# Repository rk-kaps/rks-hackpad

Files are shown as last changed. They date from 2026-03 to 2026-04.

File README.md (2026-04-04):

<h1 align="center">12-Key RP2040 Hackpad</h1>

<p align="center">
  A custom 12-key macropad built around the Seeed XIAO RP2040, featuring per-key RGB, an OLED display, and a 3D printed case.
</p>

<p align="center">
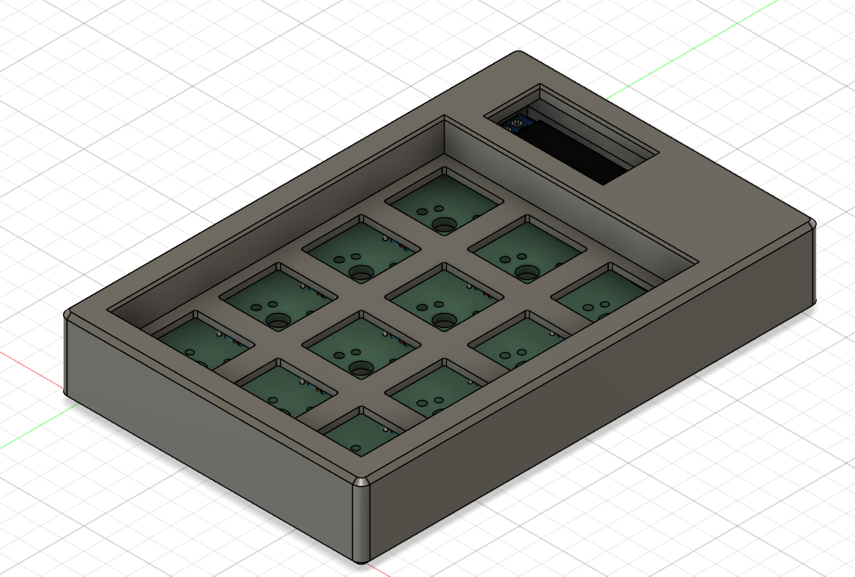
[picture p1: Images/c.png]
Hackpad Main
  
</p>

<hr>

<h2>Motivation</h2>
<ul>

This Hackpad began as a simple volume controller. It evolved into a fully-featured macropad focused on:

- Speeding up workflows
- Reducing repetitive actions
- Providing intuitive visual feedback
- Maximizing functionality within hardware constraints

</ul>

<h2>Project Highlights</h2>
<ul>

- Dual-core RP2040 at up to 133MHz via the compact Seeed XIAO form factor
- Per-key RGB lighting using SK6812 MINI-E reverse-mount LEDs for clean underglow
- 0.91" OLED display for real-time visual feedback and animations
- Keyboard matrix protected by 1N4148 diodes for reliable n-key rollover
- Brass heatset inserts for durable, reusable screw connections in the 3D printed case
- Compact 12-key layout in a custom 3D printed two-piece shell

</ul>

<h2>Firmware Features</h2>
<ul>

- Acts as a USB numpad  
- LED pulses under each key when pressed  
- OLED plays a cat GIF on loop  

</ul>

<hr>

<h2>PCB & Schematic</h2>

<p align="center">
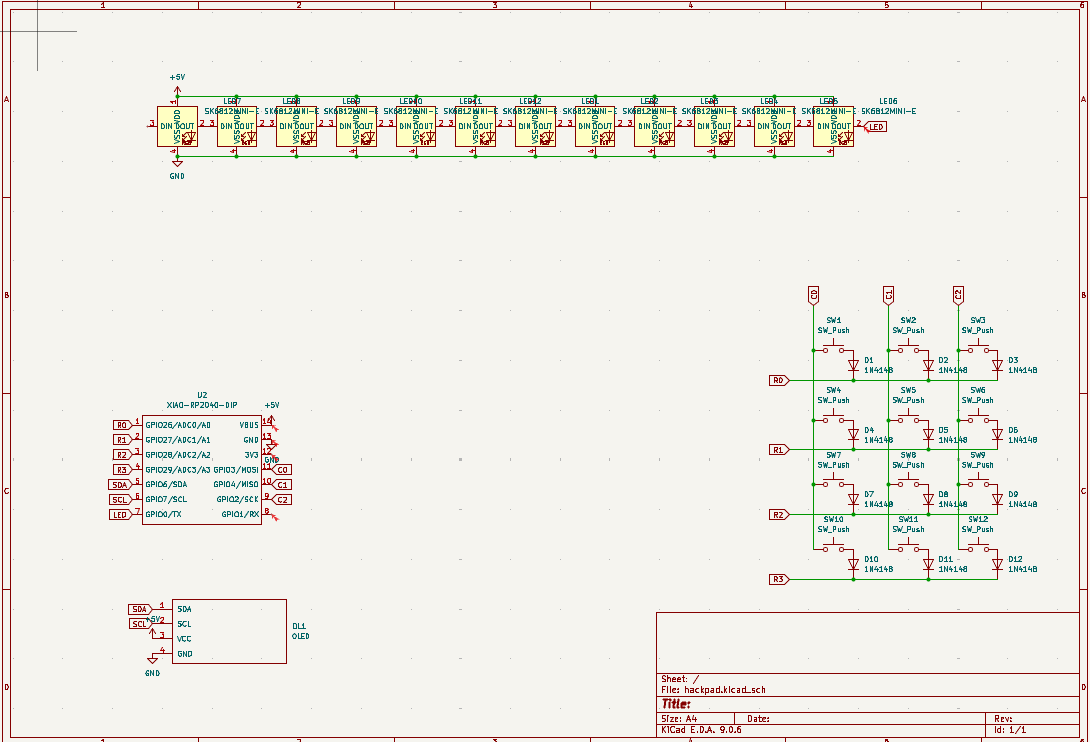
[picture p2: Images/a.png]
Schematic
  
  <br><em>Schematic</em>
</p>

<p align="center">
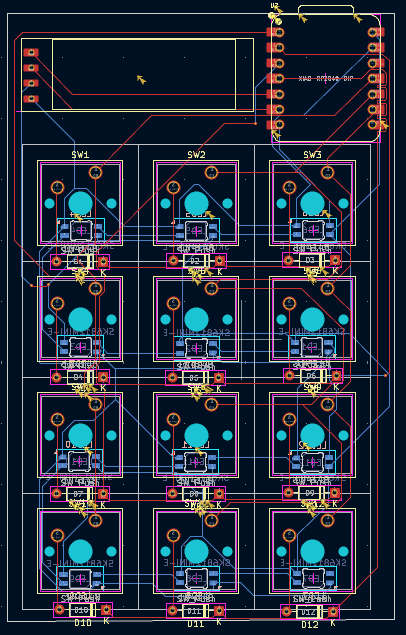
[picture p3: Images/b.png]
PCB Layout
  
  <br><em>PCB Layout (KiCad)</em>
</p>

<p align="center">
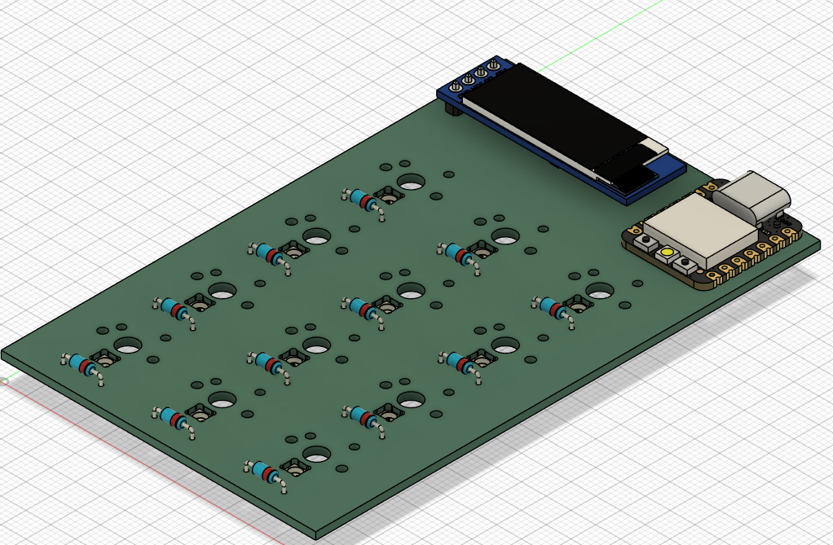
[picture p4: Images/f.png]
PCB 3D View
  
  <br><em>PCB 3D Render</em>
</p>

<hr>

<h2>Case Design</h2>

<p align="center">
  Case CAD
  <br><em>Case CAD</em>
</p>

<hr>

<h2>Bill of Materials</h2>

> A full BOM with pricing and purchase links is available as a separate file.

| Part | Quantity |
|---|---|
| Seeed XIAO RP2040 | 1 |
| MX-Style Switches | 12 |
| Through-hole 1N4148 Diodes | 12 |
| SK6812 MINI-E LEDs | 12 |
| 0.91" OLED Display (SSD1306 I2C 128×32) | 1 |
| Blank DSA Keycaps | 12 |
| M3×16 mm Cap Head Screws | 4 |
| M3×5 mm Brass Heatset Inserts | 4 |
| 3D Printed Case Top | 1 |
| 3D Printed Case Bottom | 1 |

<hr>

<h2>Firmware</h2>

Firmware is located in the `Deploy` folder. Flash directly to the RP2040 via USB drag-and-drop.

<hr>

<h2>Acknowledgements</h2>
<ul>

- Good people of Hack Club  

</ul>

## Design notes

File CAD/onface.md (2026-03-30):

https://cad.onshape.com/documents/341b59d3e8adaa2c605d270c/w/1172ec9e4d3fff75a9b2d15b/e/0eea5737da17a0d97b459e8b <---- link for onface

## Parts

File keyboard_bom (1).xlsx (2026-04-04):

Macropad Keyboard Build — Bill of Materials (India)
# | Part | Qty | Unit | Description | Unit Price (₹) | Total Price (₹) | Supplier | Buy Link
1 | Seeed XIAO RP2040 | 1 | pcs | Dual-core RP2040 MCU, USB-C, compact dev board for keyboard firmware | ₹619 | ₹619 | Robocraze | Buy Here → (https://robocraze.com/products/seeed-studio-xiao-rp2040-development-board)
2 | MX-Style Switches | 12 | pcs | Mechanical keyboard switches (Cherry MX or compatible clone, plate-mount) | ₹35 | ₹750 | Meckeys | Buy Here → (https://meckeys.com/shop/accessories/keyboard-accessories/key-switches/cherry-mx2a-switch/)
3 | Through-hole 1N4148 Diodes | 12 | pcs | Fast switching silicon diode for keyboard matrix (through-hole) | ₹3 | ₹60 | Robocraze | Buy Here → (https://robocraze.com/products/1n4148-diode-pack-of-10)
4 | PCB | 1 | pcs | pcb | ₹230.89 | ₹230.89 | jlcpcb
5 | 0.91" OLED Display (I2C) | 1 | pcs | 128×32 blue OLED display module, I2C, SSD1306 driver | ₹160 | ₹160 | Robocraze | Buy Here → (https://robocraze.com/products/0-91-inch-blue-oled-display-module)
6 | Blank DSA Keycaps | 12 | pcs | Blank PBT DSA profile keycaps, 1u, MX-compatible | ₹100 | ₹1200 | Meckeys | Buy Here → (https://meckeys.com/shop/accessories/keyboard-accessories/keycaps/blank-dsa-keycaps-1u/)
7 | M3×16 mm Screws | 4 | pcs | M3×16mm Socket Head Cap Screws (Allen drive, stainless steel) for case assembly | ₹50 | ₹50 | OnlyScrews | Buy Here → (https://onlyscrews.in/products/m3-x-16mm-hex-allen-csk-high-tensile10-9-black-oxide-screw-dia-3mm-length-16mm)
8 | M3×5 mm Heatset Inserts | 4 | pcs | Brass M3×5mm heatset threaded inserts for 3D-printed case bottom | ₹40 | ₹40 | OnlyScrews | Buy Here → (https://onlyscrews.in/products/m3-x-5mm-brass-threaded-inserts-dia-3mm-length-5mm?variant=50139409973561)
9 | Case Top (3D Printed) | 1 | pcs | Top shell of keyboard case — 3D print using PLA/PETG from your own design files | ₹200 | ₹200 | Local 3D Print Service
10 | Case Bottom (3D Printed) | 1 | pcs | Bottom shell of keyboard case — 3D print using PLA/PETG from your own design files | ₹200 | ₹200 | Local 3D Print Service
 | GRAND TOTAL |  |  |  |  | ₹3231

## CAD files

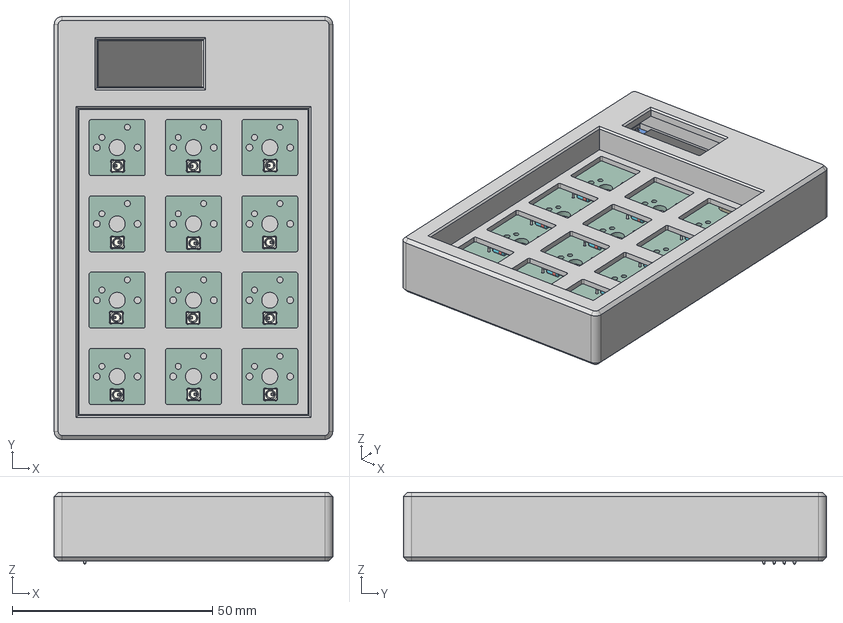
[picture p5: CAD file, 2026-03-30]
CAD/hackpad (2).step
69.5 x 105.6 x 18.0 mm
D_DO-35_SOD27_P7.62mm_Horizontal x 12
LED_SK6812MINI-E x 12
hackpad_PCB
Tiny stuff
LED
LED_1
Programmer port or something
USB-C bits
Power probably
Right
Left
OLED_0.91_128x32
Pin Header 4 x 1 TH 2.54mm Pitch
RESC-0603 x 13
2SD0601A

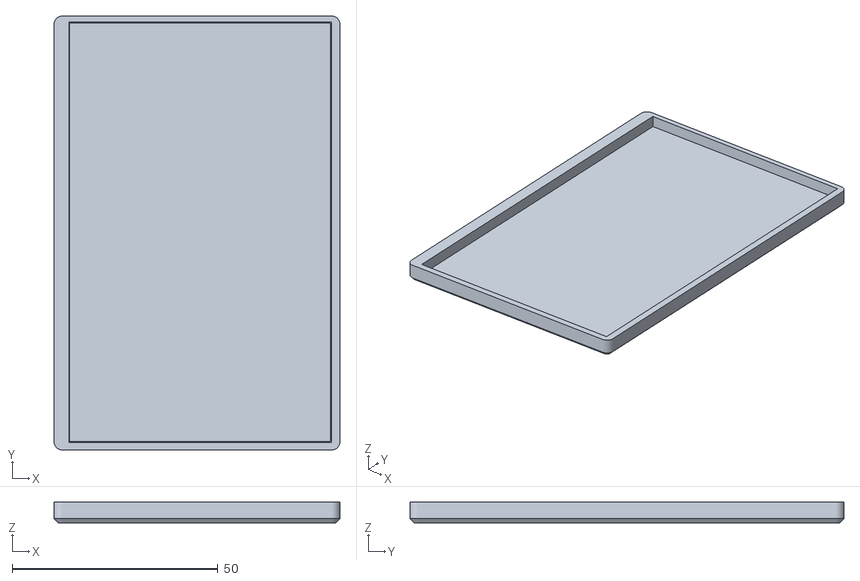
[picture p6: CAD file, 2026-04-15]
CAD/split hackpad/hackpad base2.obj
69.5 x 105.6 x 5.00

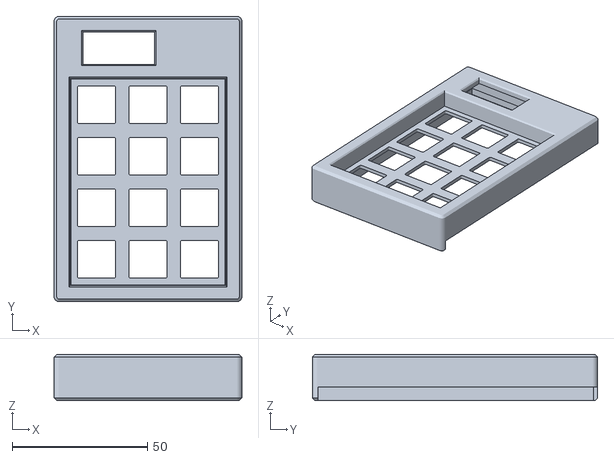
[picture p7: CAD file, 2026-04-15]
CAD/split hackpad/hackpad-hackpada v3 v1Cut.obj
69.5 x 105.6 x 17.2

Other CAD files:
CAD/split hackpad/hackpad sidepanel.obj
CAD/hackpad_.f3d

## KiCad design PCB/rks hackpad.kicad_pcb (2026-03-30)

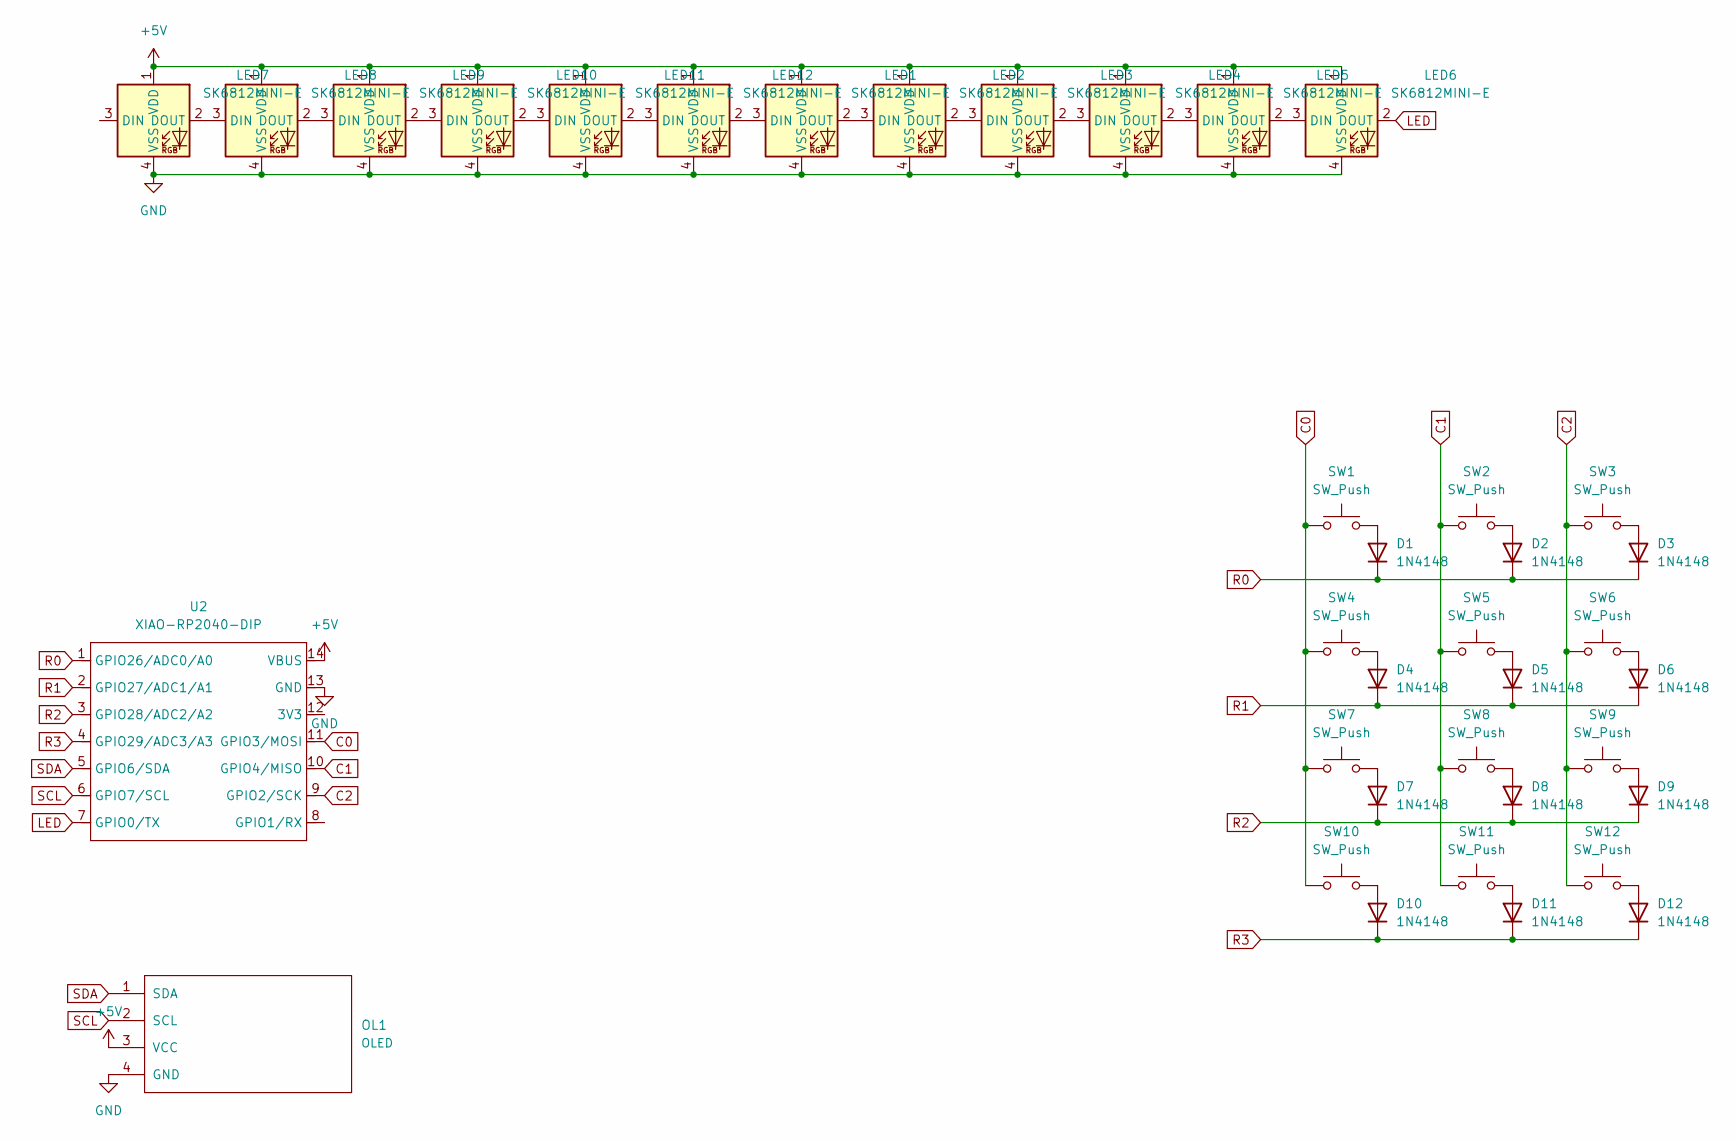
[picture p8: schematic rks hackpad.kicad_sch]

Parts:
D1, D2, D3, D4, D5, D6, D7, D8, D9, D10, D11, D12: 1N4148; D_DO-35_SOD27_P7.62mm_Horizontal
LED1, LED2, LED3, LED4, LED5, LED6, LED7, LED8, LED9, LED10, LED11, LED12: SK6812MINI-E; LED_6028R
OL1: OLED; Adafruit_SSD1306
SW1, SW2, SW3, SW4, SW5, SW6, SW7, SW8, SW9, SW10, SW11, SW12: SW_Push; SW_Cherry_MX_1.00u_PCB
U2: XIAO-RP2040-DIP

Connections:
+5V: LED1.1 (VDD), LED2.1 (VDD), LED3.1 (VDD), LED4.1 (VDD), LED5.1 (VDD), LED6.1 (VDD), LED7.1 (VDD), LED8.1 (VDD), LED9.1 (VDD), LED10.1 (VDD), LED11.1 (VDD), LED12.1 (VDD), OL1.3 (VCC), U2.14 (VBUS)
C0: SW1.1, SW4.1, SW7.1, SW10.1, U2.11 (GPIO3/MOSI)
C1: SW2.1, SW5.1, SW8.1, SW11.1, U2.10 (GPIO4/MISO)
C2: SW3.1, SW6.1, SW9.1, SW12.1, U2.9 (GPIO2/SCK)
GND: LED1.4 (VSS), LED2.4 (VSS), LED3.4 (VSS), LED4.4 (VSS), LED5.4 (VSS), LED6.4 (VSS), LED7.4 (VSS), LED8.4 (VSS), LED9.4 (VSS), LED10.4 (VSS), LED11.4 (VSS), LED12.4 (VSS), OL1.4 (GND), U2.13 (GND)
LED: LED6.2 (DOUT), U2.7 (GPIO0/TX)
unnamed: D1.2 (A), SW1.2
unnamed: D2.2 (A), SW2.2
unnamed: D3.2 (A), SW3.2
unnamed: D4.2 (A), SW4.2
unnamed: D5.2 (A), SW5.2
unnamed: D6.2 (A), SW6.2
unnamed: D7.2 (A), SW7.2
unnamed: D8.2 (A), SW8.2
unnamed: D9.2 (A), SW9.2
unnamed: D10.2 (A), SW10.2
unnamed: D11.2 (A), SW11.2
unnamed: D12.2 (A), SW12.2
unnamed: LED1.3 (DIN), LED12.2 (DOUT)
unnamed: LED1.2 (DOUT), LED2.3 (DIN)
unnamed: LED2.2 (DOUT), LED3.3 (DIN)
unnamed: LED3.2 (DOUT), LED4.3 (DIN)
unnamed: LED4.2 (DOUT), LED5.3 (DIN)
unnamed: LED5.2 (DOUT), LED6.3 (DIN)
unnamed: LED7.2 (DOUT), LED8.3 (DIN)
unnamed: LED8.2 (DOUT), LED9.3 (DIN)
unnamed: LED9.2 (DOUT), LED10.3 (DIN)
unnamed: LED10.2 (DOUT), LED11.3 (DIN)
unnamed: LED11.2 (DOUT), LED12.3 (DIN)
R0: D1.1 (K), D2.1 (K), D3.1 (K), U2.1 (GPIO26/ADC0/A0)
R1: D4.1 (K), D5.1 (K), D6.1 (K), U2.2 (GPIO27/ADC1/A1)
R2: D7.1 (K), D8.1 (K), D9.1 (K), U2.3 (GPIO28/ADC2/A2)
R3: D10.1 (K), D11.1 (K), D12.1 (K), U2.4 (GPIO29/ADC3/A3)
SCL: OL1.2 (SCL), U2.6 (GPIO7/SCL)
SDA: OL1.1 (SDA), U2.5 (GPIO6/SDA)

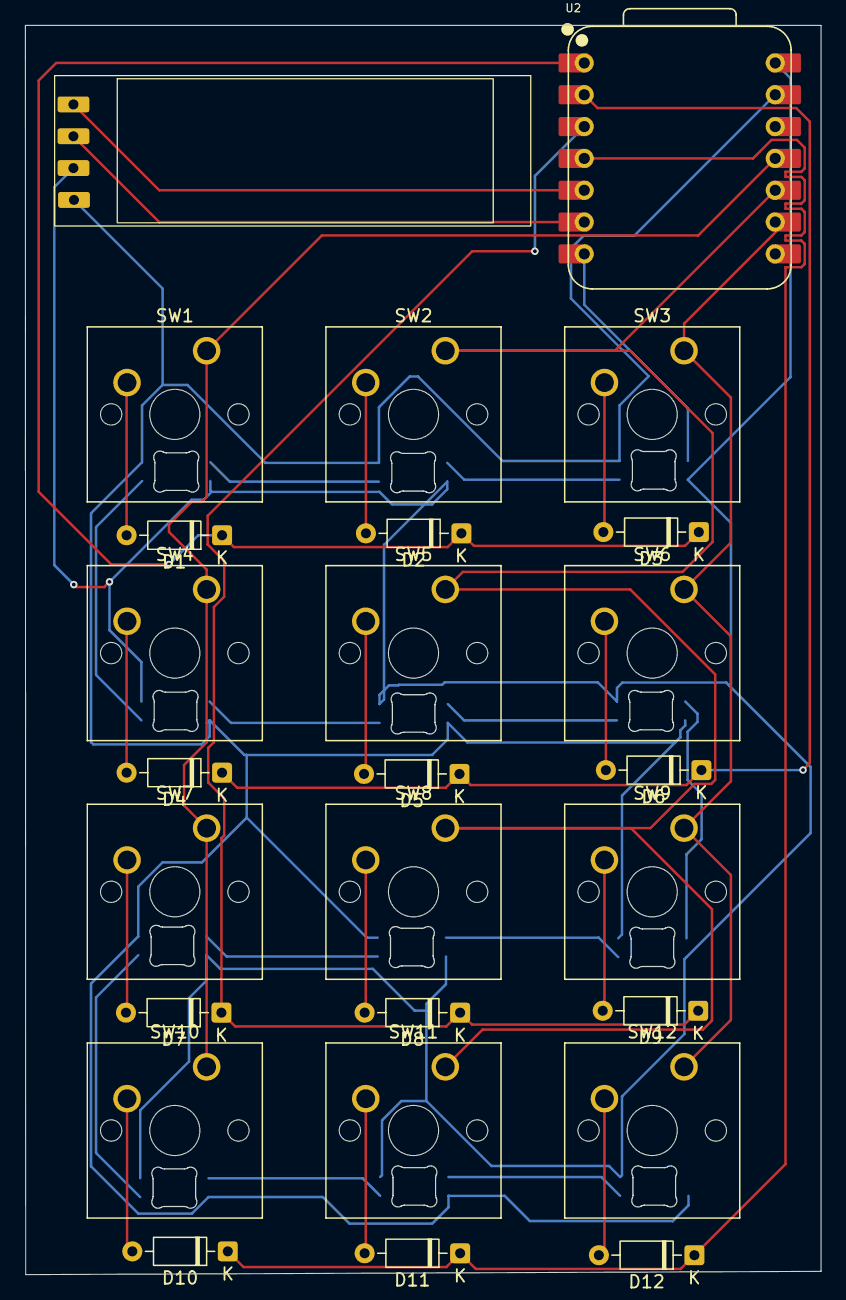
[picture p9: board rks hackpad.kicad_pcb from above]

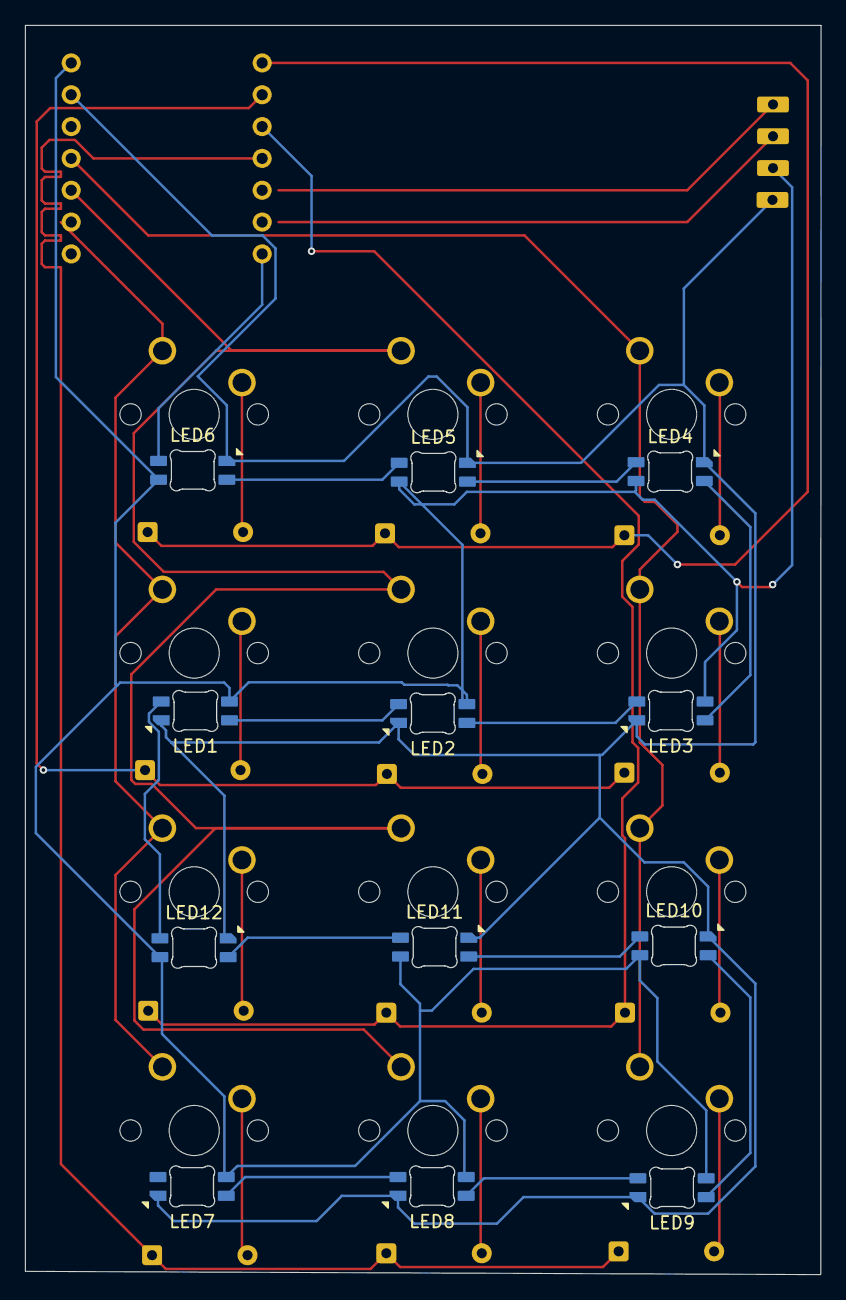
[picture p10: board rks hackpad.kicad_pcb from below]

Board: 2 copper layers, 63.5 x 99.7 mm, 38 parts (12 on the bottom side), 35 nets.

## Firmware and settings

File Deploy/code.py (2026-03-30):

import board
import digitalio
import neopixel
import time
import usb_hid
from adafruit_hid.keyboard import Keyboard
from adafruit_hid.keycode import Keycode
import displayio
import adafruit_displayio_ssd1306
from i2cdisplaybus import I2CDisplayBus
import os

class KeyScan:
    def __init__(self):
        self.rows_pins = [board.D10, board.D9, board.D8]
        self.cols_pins = [board.D0, board.D1, board.D2, board.D3]

        self.NUM_COLS = 4
        self.NUM_ROWS = 3

        self.keycode_map = {
            (0, 0): Keycode.SEVEN, (0, 1): Keycode.EIGHT, (0, 2): Keycode.NINE,
            (1, 0): Keycode.FOUR, (1, 1): Keycode.FIVE, (1, 2): Keycode.SIX,
            (2, 0): Keycode.ONE, (2, 1): Keycode.TWO, (2, 2): Keycode.THREE,
            (3, 0): Keycode.WINDOWS, (3, 1): Keycode.ZERO, (3, 2): Keycode.PERIOD
        }

        self.rows = [digitalio.DigitalInOut(p) for p in self.rows_pins]
        for r in self.rows:
            r.direction = digitalio.Direction.INPUT
            r.pull = digitalio.Pull.UP

        self.cols = [digitalio.DigitalInOut(p) for p in self.cols_pins]
        for c in self.cols:
            c.direction = digitalio.Direction.OUTPUT
            c.value = True

        self.keyboard = Keyboard(usb_hid.devices)
        self.pressed_prev = set()

    def scan(self):
        pressed = set()
        for c_idx, col in enumerate(self.cols):
            col.value = False
            for r_idx, row in enumerate(self.rows):
                if not row.value:
                    pressed.add((c_idx, r_idx))
            col.value = True
        return pressed

    def send_hid(self, pressed):
        for key in pressed - self.pressed_prev:
            try:
                self.keyboard.press(self.keycode_map[key])
            except:
                pass

        for key in self.pressed_prev - pressed:
            try:
                self.keyboard.release(self.keycode_map[key])
            except:
                pass

        self.pressed_prev = pressed


class NeoPixels:
    def __init__(self):
        self.NUM_COLS = 4
        self.NUM_ROWS = 3

        self.NUM_PIXELS = 12
        self.LED_PIN = board.D6

        self.DIM = 0.3
        self.BRIGHT = 1.0
        self.PRESS_RAMP = 0.1
        self.FADE_MAIN = 0.008
        self.FADE_NEIGH = 0.02
        self.SPREAD_DELAY = 0.01

        self.key_to_led = {
            (0, 0): 9, (0, 1): 10, (0, 2): 11,
            (1, 0): 8, (1, 1): 7, (1, 2): 6,
            (2, 0): 3, (2, 1): 4, (2, 2): 5,
            (3, 0): 2, (3, 1): 1, (3, 2): 0
        }

        self.pixels = neopixel.NeoPixel(self.LED_PIN, self.NUM_PIXELS, auto_write=False)
        self.key_state = {}
        self.neighbors = {}

        self.pixels.fill((int(150*self.DIM), int(2*self.DIM), int(255*self.DIM)))
        self.pixels.show()

    def get_neighbors(self, c, r):
        out = []
        for dc, dr in [(-1,0),(1,0),(0,-1),(0,1)]:
            nc, nr = c+dc, r+dr
            if 0 <= nc < self.NUM_COLS and 0 <= nr < self.NUM_ROWS:
                out.append((nc, nr))
        return out

    def update(self, pressed):
        now = time.monotonic()

        for key in pressed:
            if key not in self.key_state:
                self.key_state[key] = {'time': now, 'neighbors': False}

            elapsed = now - self.key_state[key]['time']
            ramp = min(elapsed / self.PRESS_RAMP, 1.0)

            idx = self.key_to_led[key]
            b = self.DIM + ramp * (self.BRIGHT - self.DIM)
            self.pixels[idx] = (int(150*b), int(2*b), int(255*b))

            if not self.key_state[key]['neighbors'] and elapsed > self.SPREAD_DELAY:
                for n in self.get_neighbors(*key):
                    self.neighbors[self.key_to_led[n]] = self.BRIGHT
                self.key_state[key]['neighbors'] = True

        for idx in list(self.neighbors):
            self.neighbors[idx] -= self.FADE_NEIGH
            if self.neighbors[idx] <= self.DIM:
                self.neighbors.pop(idx)
                self.pixels[idx] = (int(150*self.DIM), int(2*self.DIM), int(255*self.DIM))
            else:
                self.pixels[idx] = (int(150*self.neighbors[idx]), int(2*self.neighbors[idx]), int(255*self.neighbors[idx]))

        for key in list(self.key_state):
            if key not in pressed:
                idx = self.key_to_led[key]
                r = self.pixels[idx][0] / 150
                r -= self.FADE_MAIN
                if r <= self.DIM:
                    self.key_state.pop(key)
                    r = self.DIM
                self.pixels[idx] = (int(150*r), int(2*r), int(255*r))

        self.pixels.show()

class OLED:
    def __init__(self):
        displayio.release_displays()

        i2c = board.I2C()
        display_bus = I2CDisplayBus(i2c, device_address=0x3C)

        self.display = adafruit_displayio_ssd1306.SSD1306(
            display_bus,
            width=128,
            height=32
        )

        self.display.auto_refresh = True

        main_group = displayio.Group()
        self.display.root_group = main_group

        bmp_folder = "/animation_bmps"
        filenames = sorted(f for f in os.listdir(bmp_folder) if f.endswith(".bmp"))

        bitmap_files = []
        self.bitmaps = []

        for name in filenames:
            f = open(bmp_folder + "/" + name, "rb")
            bmp = displayio.OnDiskBitmap(f)
            bitmap_files.append(f)
            self.bitmaps.append(bmp)

        self.tile_grid = displayio.TileGrid(
            self.bitmaps[0],
            pixel_shader=self.bitmaps[0].pixel_shader
        )

        main_group.append(self.tile_grid)
        self.display.refresh()
        
        self.frame_index = 0
        self.total_frames = len(self.bitmaps)
        
    def update_oled(self):
        self.tile_grid.bitmap = self.bitmaps[self.frame_index]
        self.frame_index = (self.frame_index + 1) % self.total_frames

oled = OLED()
scanner = KeyScan()
leds = NeoPixels()
last_oled_time = 0


while True:
    startTime = time.monotonic()

    pressed = scanner.scan()
    scanner.send_hid(pressed)
    
    if time.monotonic() - last_oled_time >= 0.2:
        oled.update_oled()
        last_oled_time = time.monotonic()
            
    leds.update(pressed)
    
    elapsed = time.monotonic() - startTime

    if elapsed < 0.001:
        time.sleep(0.001 - elapsed)
